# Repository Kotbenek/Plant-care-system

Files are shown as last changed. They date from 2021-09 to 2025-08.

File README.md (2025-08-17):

# Moved to Codeberg

This repository was moved to Codeberg:
https://codeberg.org/Kotbenek/Plant-care-system

# Plant care system
PCB of the Plant care system

## Board overview

- ATmega32 AVR microcontroller as the heart of the Plant care system
- Terminal block connector for external pump
- Galvanically isolated terminal block connector for external lamp
- AVR ISP connector for AVR programming
- 5V DC input with battery backup:
  - 18650 battery holder for battery operation
  - TP4056 board for battery charging
  - Additional circuitry enabling simultaneous battery charging and system operation
- Microswitch buttons for system parameters setup
- 4-digit 7-segment display for system parameters
- LEDs indicating the currently displayed parameter on 7-segment display

## Images

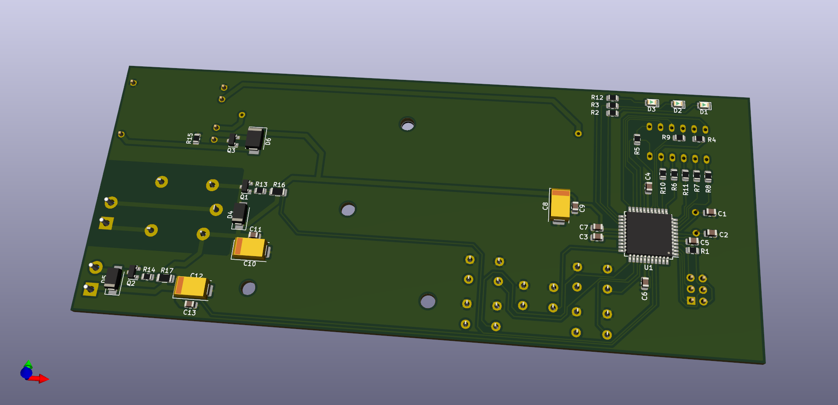
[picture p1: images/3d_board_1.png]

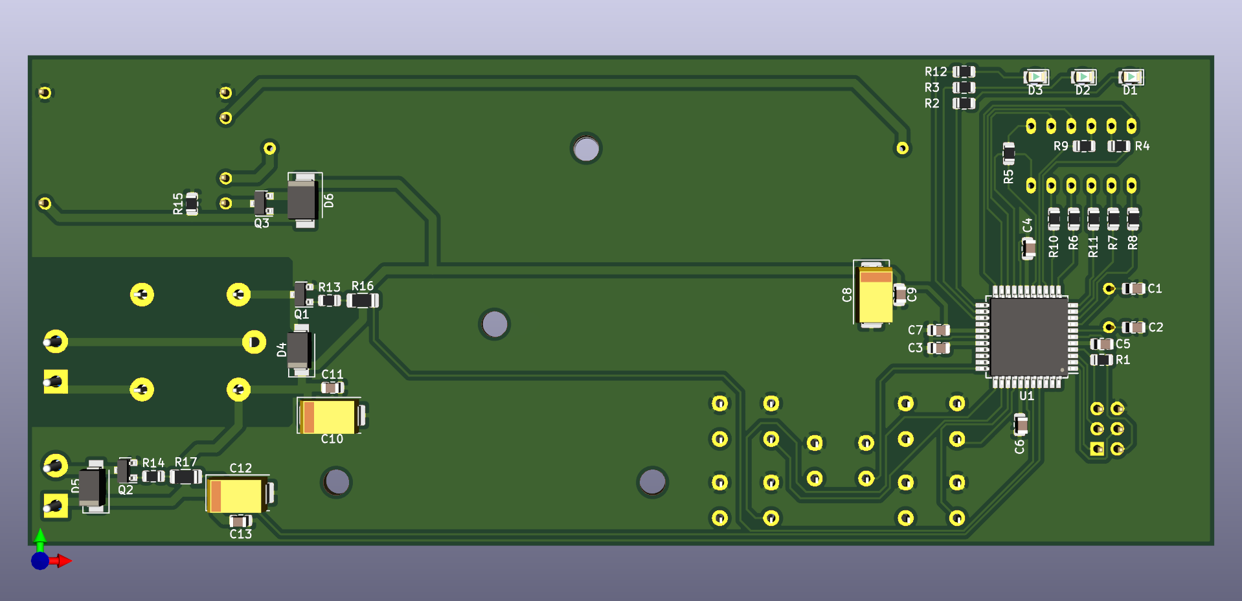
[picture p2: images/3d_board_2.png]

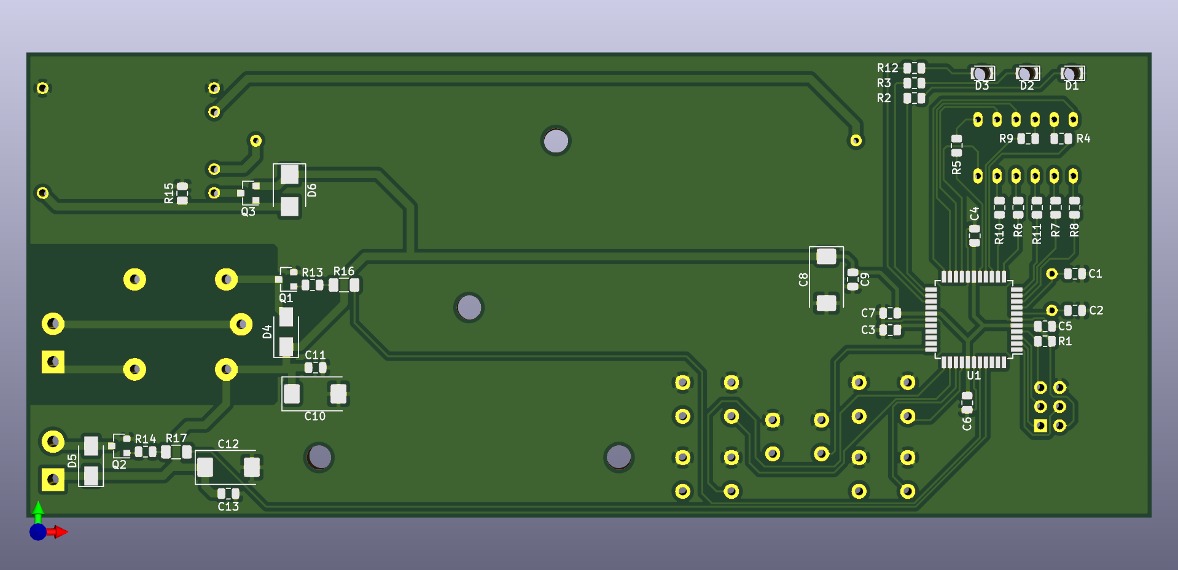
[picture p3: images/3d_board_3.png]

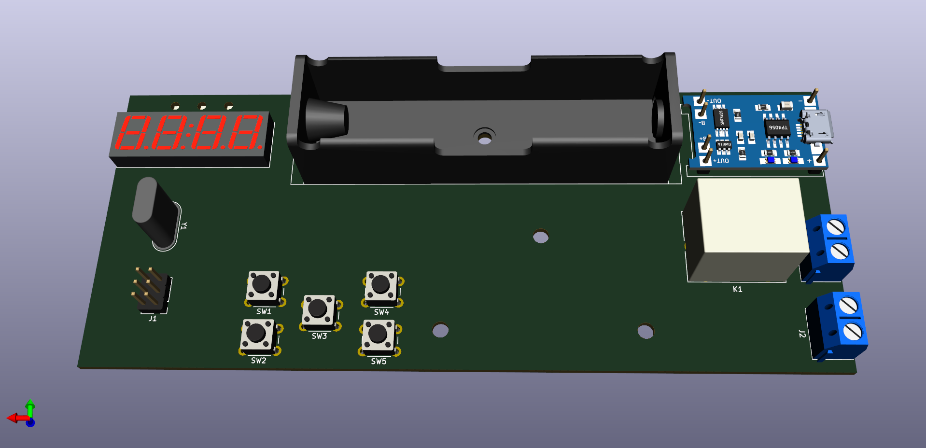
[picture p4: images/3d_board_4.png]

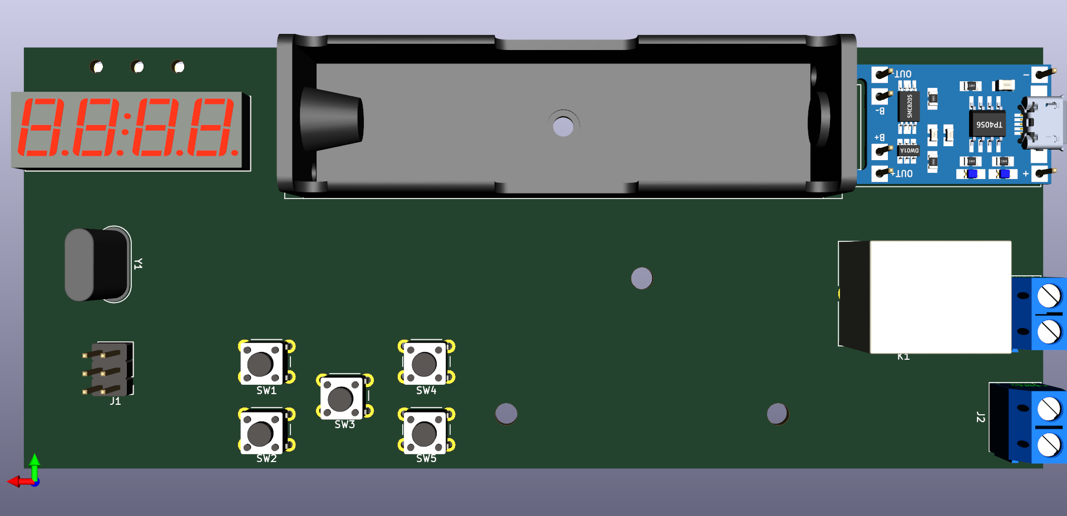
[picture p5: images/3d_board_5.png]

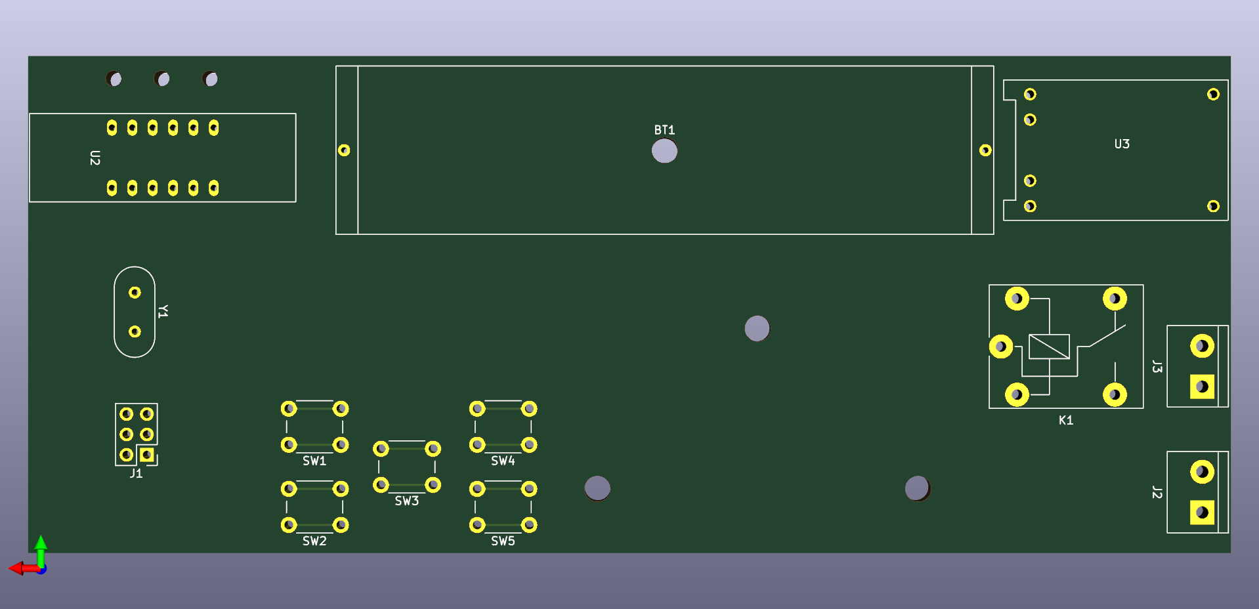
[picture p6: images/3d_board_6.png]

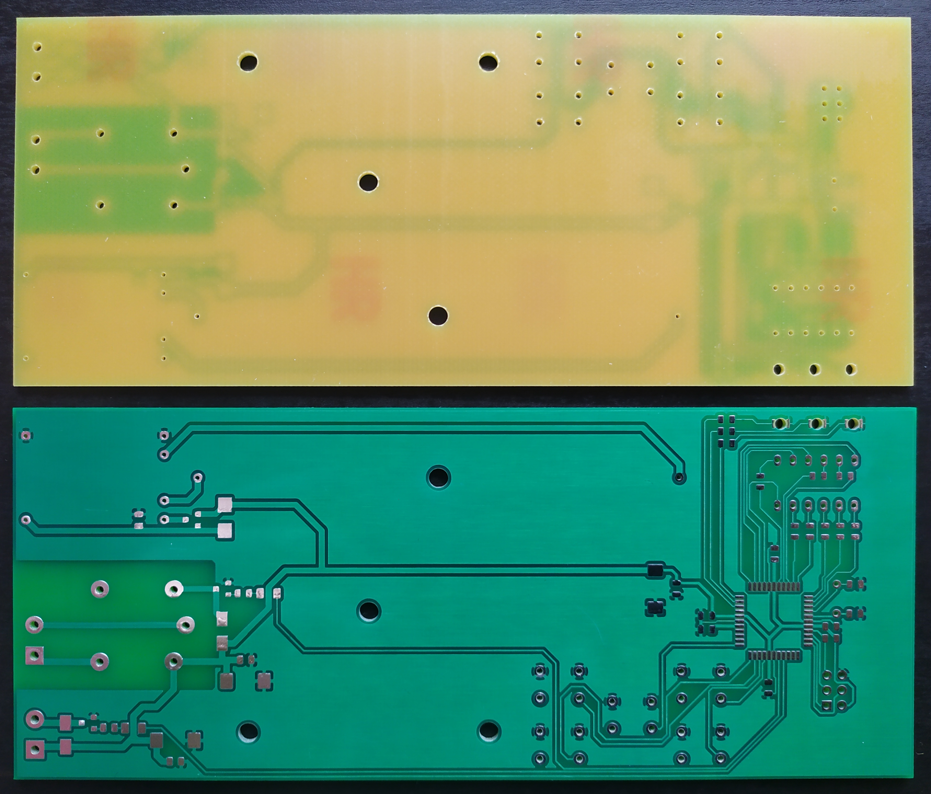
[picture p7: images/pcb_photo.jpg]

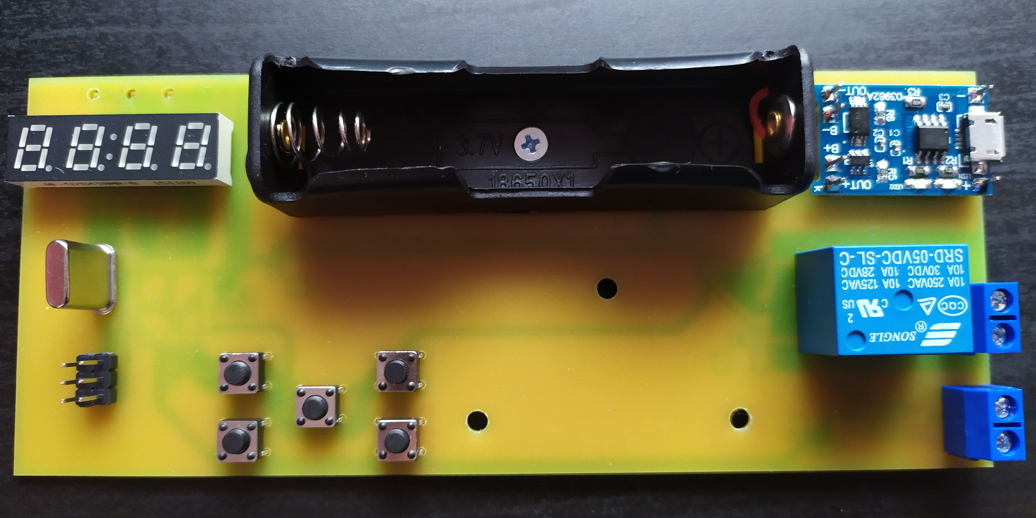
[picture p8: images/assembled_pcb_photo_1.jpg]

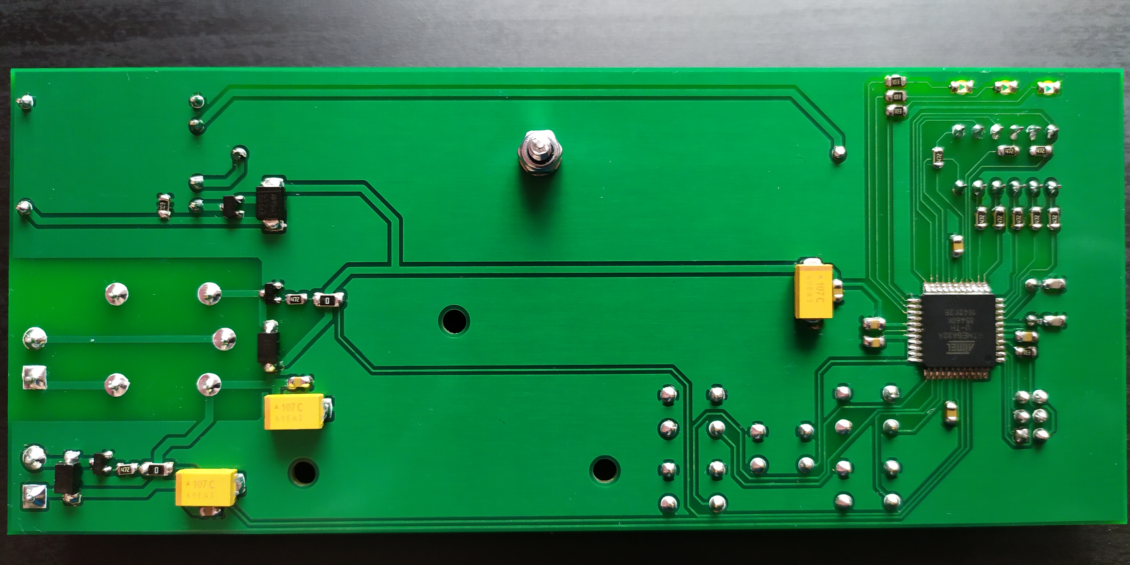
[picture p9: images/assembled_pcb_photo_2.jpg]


## External 3D models used in the PCB render

- [TP4056 module](https://grabcad.com/library/03962a-hw107-lithium-battery-charging-module-1)
- [18650 battery holder](https://grabcad.com/library/18650-single-slot-battery-holder-leaded-1)
- [Terminal block](https://grabcad.com/library/degson-dg301-series-5-0mm-terminal-block-pack-1)

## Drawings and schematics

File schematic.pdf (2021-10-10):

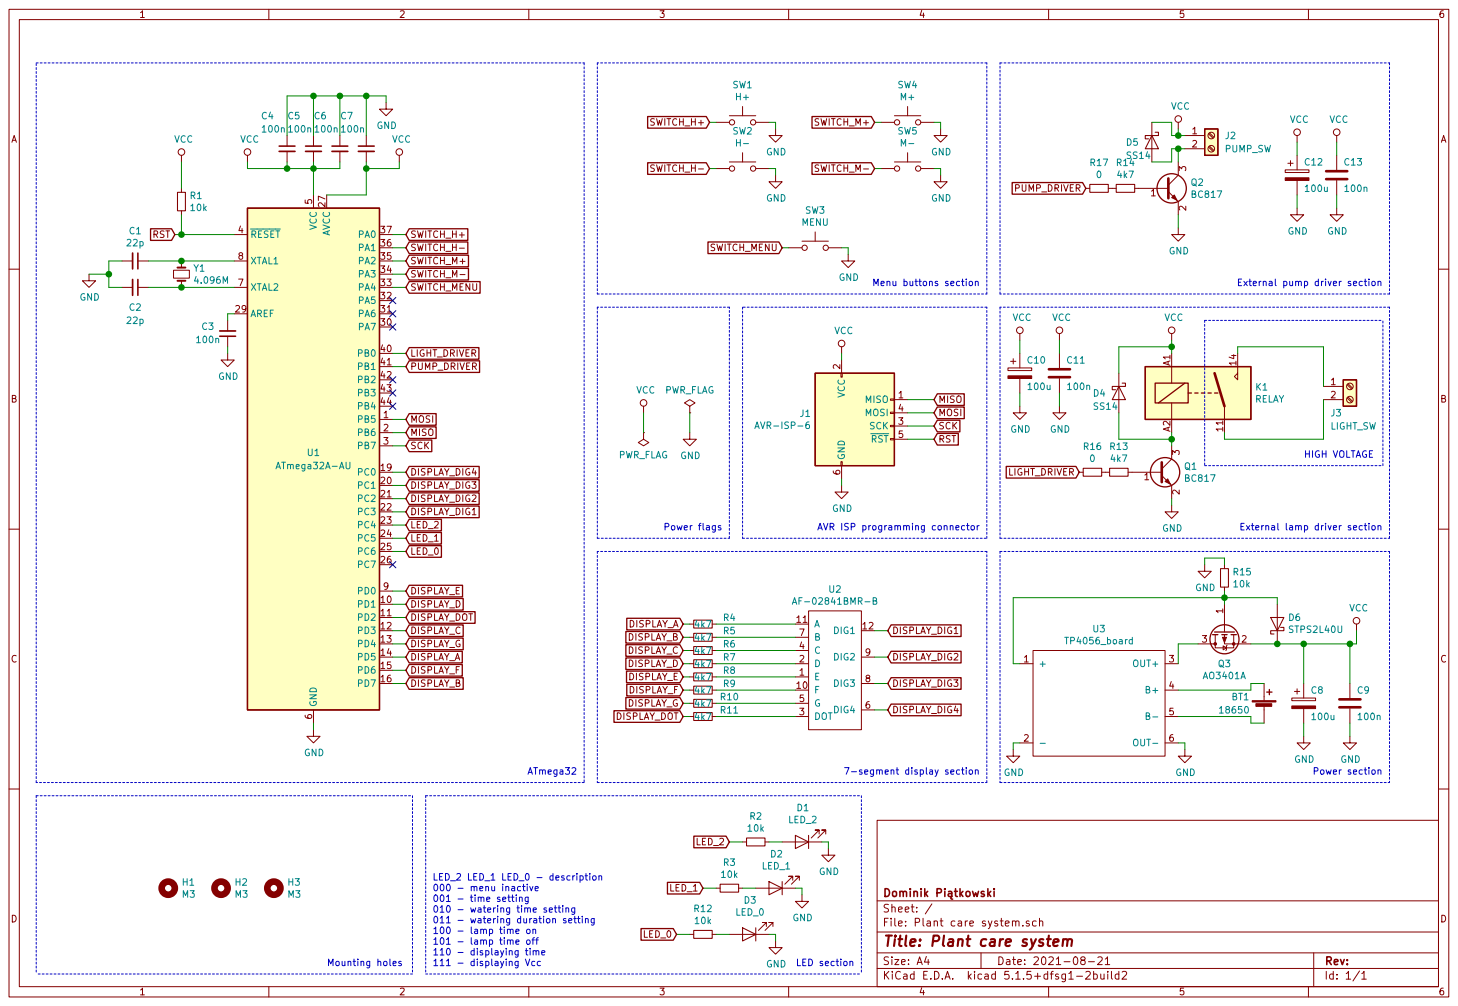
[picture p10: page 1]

External pump driver section

2 SCK 3 MOSI 4 RST 5 GND

AVR ISP programming connector

File: Plant care system.sch Sheet: / Dominik Pitkowski

Id: 1/1 Title: Plant care system

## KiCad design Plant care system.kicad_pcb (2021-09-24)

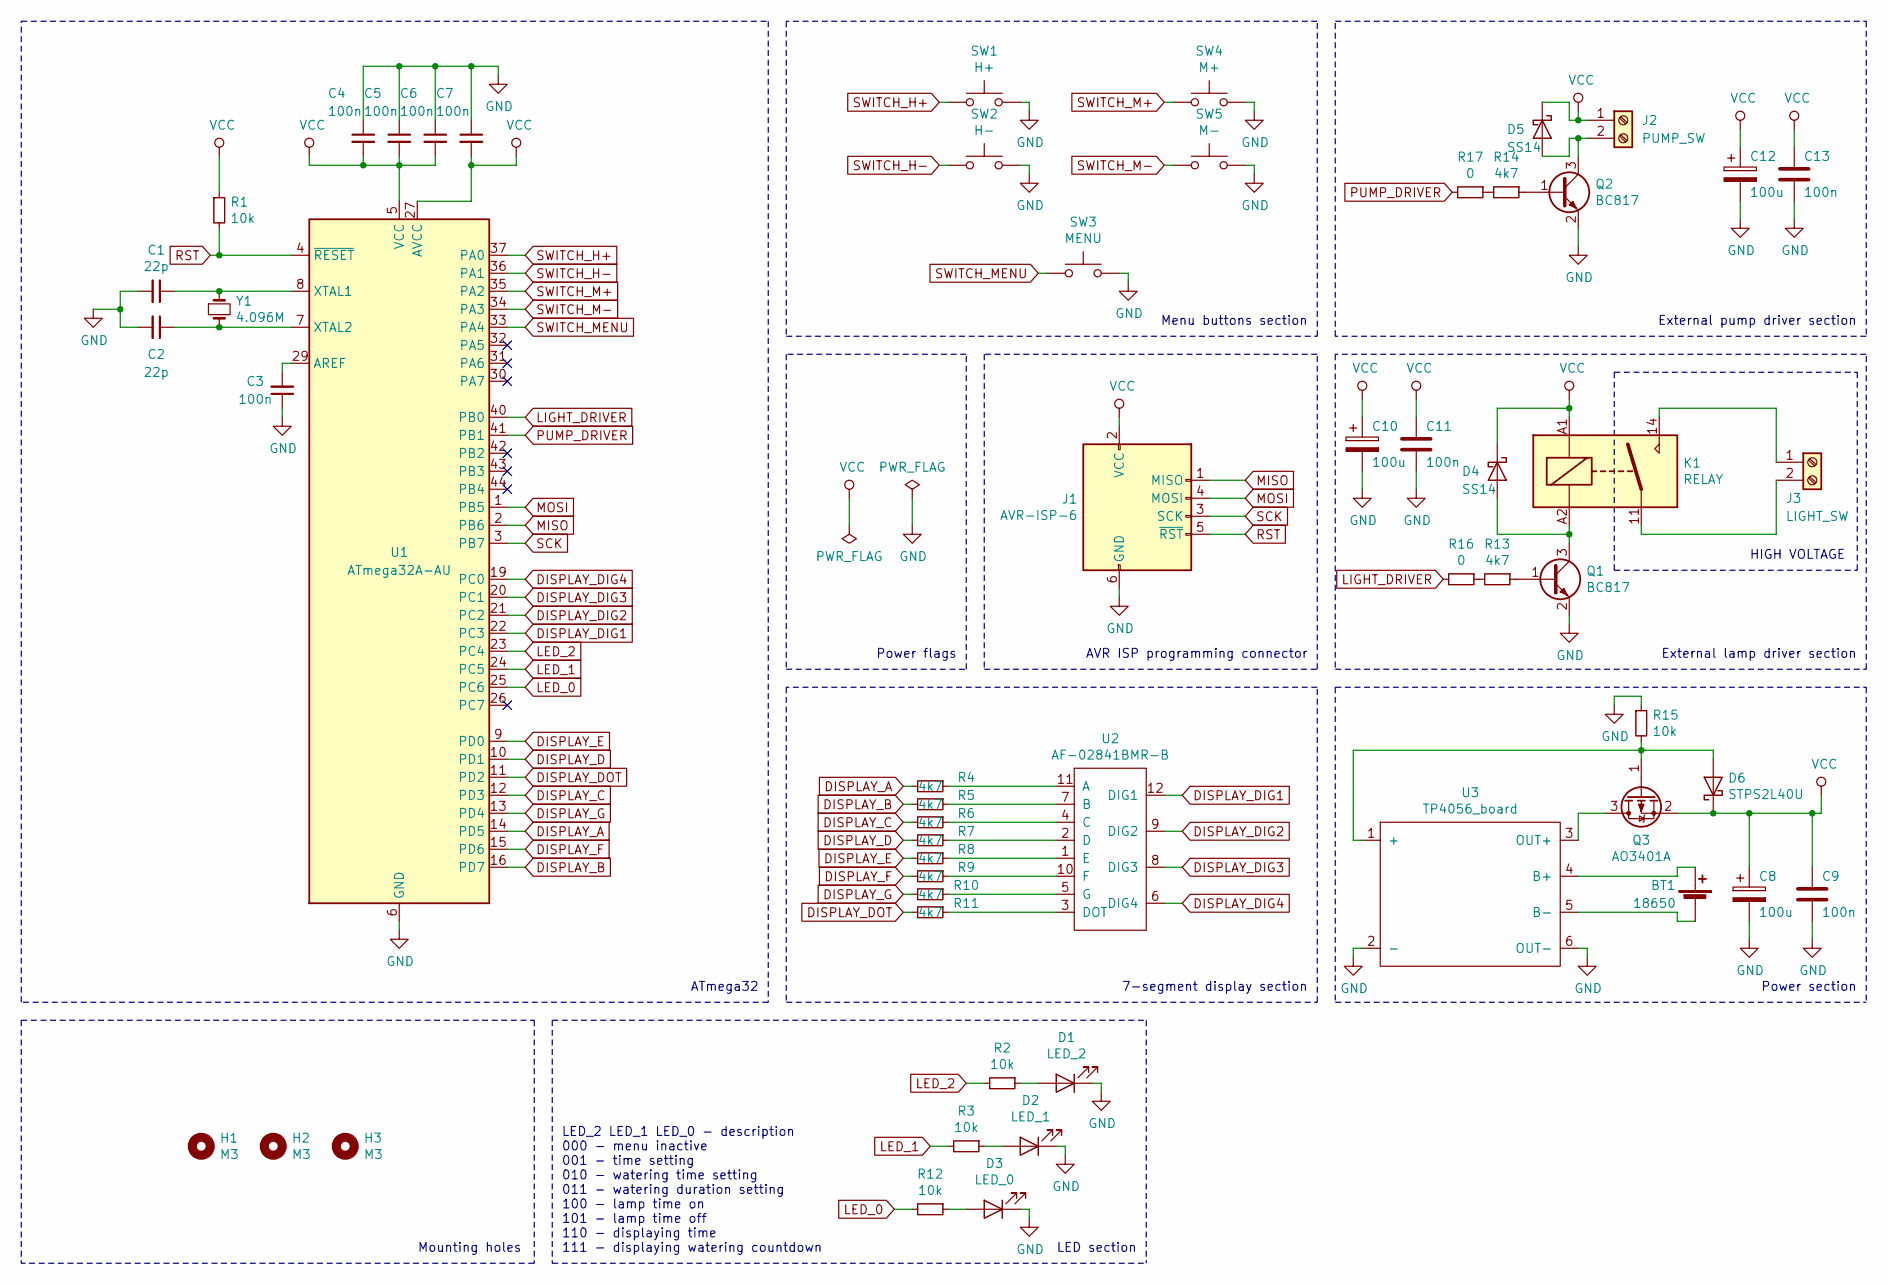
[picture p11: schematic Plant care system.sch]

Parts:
BT1: 18650; 18650_holder
C1, C2: 22p; C_0805_2012Metric
C3, C4, C5, C6, C7, C9, C11, C13: 100n; C_0805_2012Metric
C8, C10, C12: 100u; CP_EIA-7343-31_Kemet-D
D1: LED_2; LED_0805_2012Metric
D2: LED_1; LED_0805_2012Metric
D3: LED_0; LED_0805_2012Metric
D4, D5: SS14; D_SMA
D6: STPS2L40U; D_SMB
H1, H2, H3: M3; MountingHole_3.2mm_M3
J1: AVR-ISP-6; PinHeader_2x03_P2.54mm_Vertical
J2: PUMP_SW; DG-301
J3: LIGHT_SW; DG-301
K1: RELAY; Relay_SPDT_Finder_36.11
Q1, Q2: BC817; SOT-23
Q3: AO3401A; SOT-23
R1, R2, R3, R12, R15: 10k; R_0805_2012Metric
R4, R5, R6, R7, R8, R9, R10, R11, R13, R14: 4k7; R_0805_2012Metric
R16, R17: 0; R_1206_3216Metric
SW1: H+; SW_PUSH_6mm_H5mm
SW2: H-; SW_PUSH_6mm_H5mm
SW3: MENU; SW_PUSH_6mm_H5mm
SW4: M+; SW_PUSH_6mm_H5mm
SW5: M-; SW_PUSH_6mm_H5mm
U1: ATmega32A-AU; TQFP-44_10x10mm_P0.8mm
U2: AF-02841BMR-B
U3: TP4056_board
Y1: 4.096M; Crystal_HC49-U_Vertical

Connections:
DISPLAY_A: R4.2, U1.14 (PD5)
DISPLAY_B: R5.2, U1.16 (PD7)
DISPLAY_C: R6.2, U1.12 (PD3)
DISPLAY_D: R7.2, U1.10 (PD1)
DISPLAY_DIG1: U1.22 (PC3), U2.12 (DIG1)
DISPLAY_DIG2: U1.21 (PC2), U2.9 (DIG2)
DISPLAY_DIG3: U1.20 (PC1), U2.8 (DIG3)
DISPLAY_DIG4: U1.19 (PC0), U2.6 (DIG4)
DISPLAY_DOT: R11.2, U1.11 (PD2)
DISPLAY_E: R8.2, U1.9 (PD0)
DISPLAY_F: R9.2, U1.15 (PD6)
DISPLAY_G: R10.2, U1.13 (PD4)
GND: C1.2, C2.2, C3.1, C4.1, C5.1, C6.1, C7.1, C8.2, C9.2, C10.2, C11.2, C12.2, C13.2, D1.1 (K), D2.1 (K), D3.1 (K), J1.6 (GND), Q1.2 (E), Q2.2 (E), R15.1, SW1.2, SW2.2, SW3.2, SW4.2, SW5.2, U1.6 (GND), U1.18 (GND), U1.28 (GND), U1.39 (GND), U3.2 (-), U3.6 (OUT-)
LED_0: R12.2, U1.25 (PC6)
LED_1: R3.2, U1.24 (PC5)
LED_2: R2.2, U1.23 (PC4)
LIGHT_DRIVER: R16.2, U1.40 (PB0)
MISO: J1.1 (MISO), U1.2 (PB6)
MOSI: J1.4 (MOSI), U1.1 (PB5)
unnamed: BT1.1 (+), U3.4 (B+)
unnamed: BT1.2 (-), U3.5 (B-)
unnamed: C1.1, U1.8 (XTAL1), Y1.1
unnamed: C2.1, U1.7 (XTAL2), Y1.2
unnamed: C3.2, U1.29 (AREF)
unnamed: D1.2 (A), R2.1
unnamed: D2.2 (A), R3.1
unnamed: D3.2 (A), R12.1
unnamed: D4.2 (A), K1.A2, Q1.3 (C)
unnamed: D5.2 (A), J2.2, Q2.3 (C)
unnamed: D6.2 (A), Q3.1 (G), R15.2, U3.1 (+)
unnamed: J3.1, K1.14
unnamed: J3.2, K1.11
unnamed: Q1.1 (B), R13.1
unnamed: Q2.1 (B), R14.1
unnamed: Q3.3 (D), U3.3 (OUT+)
unnamed: R4.1, U2.11 (A)
unnamed: R5.1, U2.7 (B)
unnamed: R6.1, U2.4 (C)
unnamed: R7.1, U2.2 (D)
unnamed: R8.1, U2.1 (E)
unnamed: R9.1, U2.10 (F)
unnamed: R10.1, U2.5 (G)
unnamed: R11.1, U2.3 (DOT)
unnamed: R13.2, R16.1
unnamed: R14.2, R17.1
PUMP_DRIVER: R17.2, U1.41 (PB1)
RST: J1.5 (~RST), R1.2, U1.4 (~RESET)
SCK: J1.3 (SCK), U1.3 (PB7)
SWITCH_H+: SW1.1, U1.37 (PA0)
SWITCH_H-: SW2.1, U1.36 (PA1)
SWITCH_M+: SW4.1, U1.35 (PA2)
SWITCH_M-: SW5.1, U1.34 (PA3)
SWITCH_MENU: SW3.1, U1.33 (PA4)
VCC: C4.2, C5.2, C6.2, C7.2, C8.1, C9.1, C10.1, C11.1, C12.1, C13.1, D4.1 (K), D5.1 (K), D6.1 (K), J1.2 (VCC), J2.1, K1.A1, Q3.2 (S), R1.1, U1.5 (VCC), U1.17 (VCC), U1.27 (AVCC), U1.38 (VCC)

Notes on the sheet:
Power section
External lamp driver section
External pump driver section
AVR ISP programming connector
7-segment display section
Power flags
ATmega32
Menu buttons section
LED section
LED_2 LED_1 LED_0 - description 000 - menu inactive 001 - time setting 010 - watering time setting 011 - watering duration setting 100 - lamp time on 101 - lamp time off 110 - displaying time 111 - displaying watering countdown
HIGH VOLTAGE
Mounting holes

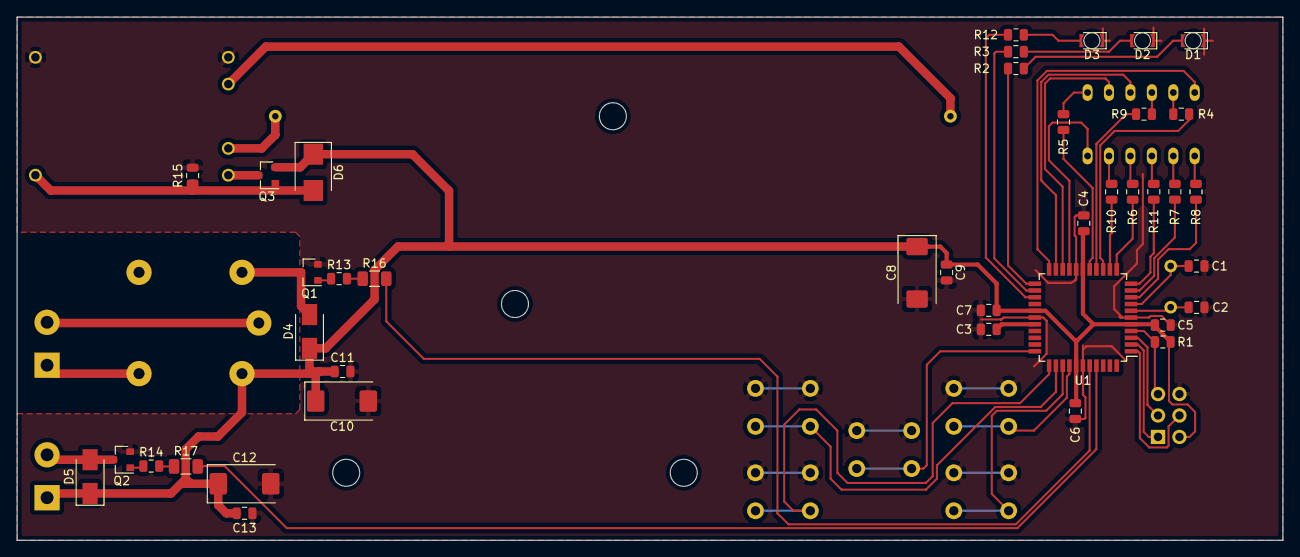
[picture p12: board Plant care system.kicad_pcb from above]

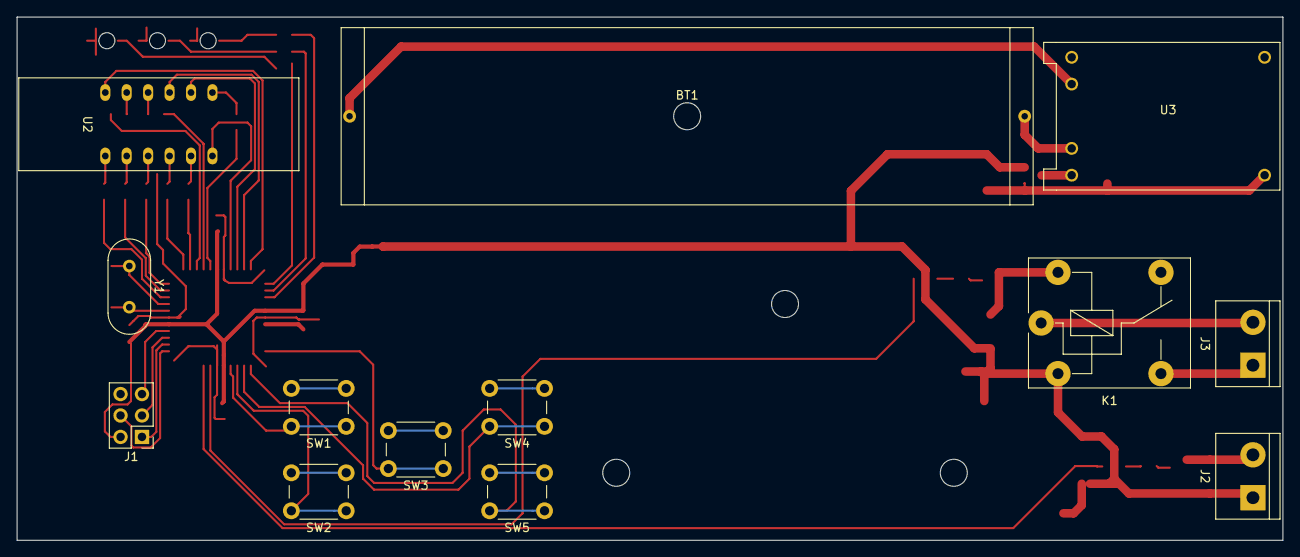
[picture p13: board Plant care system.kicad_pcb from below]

Board: 2 copper layers, 150.0 x 62.0 mm, 56 parts (16 on the bottom side), 54 nets.

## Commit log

2021-08-31 Version 1.0
    [Plant care system.kicad_pcb, Plant care system.sch]
2021-08-31 Added PCB images
2021-08-31 Added gerber files
    [Plant care system-B_SilkS.gbo, Plant care system-F_Cu.gtl, Plant care system-F_Mask.gts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]
2021-08-31 Added schematic as pdf file
2021-08-31 Minor PCB update
    - Changed gerber generation settings
    [Plant care system.kicad_pcb]
2021-09-03 Added missing gerber file
    [Plant care system.kicad_pcb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]
2021-09-24 Added PCB photo
2021-09-24 Changed TP4056 module holes to 1mm
    [Plant care system.kicad_pcb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]
2021-09-24 Updated PCB images
2021-09-28 Updated PCB images
    - Added assembled PCB photos
    - Cropped PCB photo
2021-10-10 Changed LEDs description
    [Plant care system.sch]
